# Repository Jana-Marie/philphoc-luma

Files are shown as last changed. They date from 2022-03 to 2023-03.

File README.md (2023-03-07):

# philphoc-luma

Philphoc-luma is a ZigBee (e.g. Philips Hue) to addressable LED-strip (e.g. WS2812, SK6812) bridge. It is based on an E75-2G4M20S and a STM32G030.

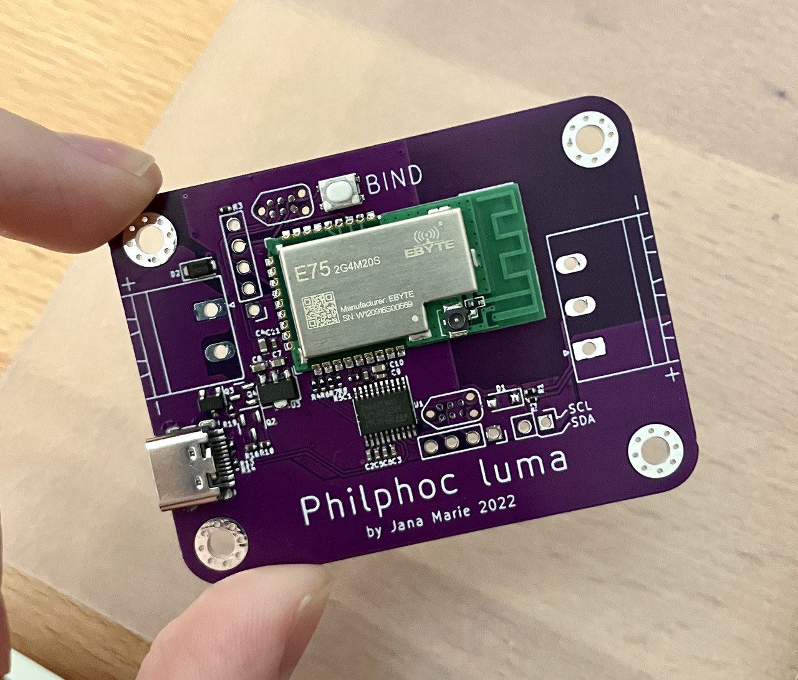
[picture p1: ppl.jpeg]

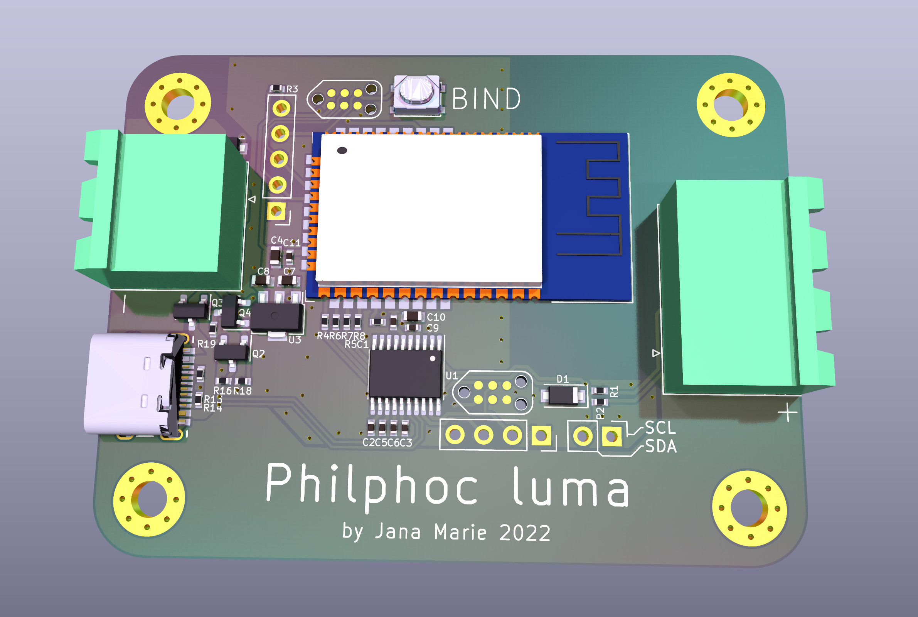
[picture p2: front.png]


## Firmware

There are two firmwares to be flashed, one for the STM32 and one for the E75-2G4M20S.

### ESP32

This is a simple GCC and Make based project, refer to the makefile and use your favourite flasher.

### E75

Please refer to the awesome works of PeeVeeOne to flash Light_ColorLight_JN5168_RGB onto the E75-2G4M20S module.

## License

Copyright Jana Marie Hemsing 2023. This source describes Open Hardware and is licensed under the CERN- OHL-S v2.

You may redistribute and modify this source and make products using it under the terms of the CERN-OHL-S v2 (LICENSE).

This source is distributed WITHOUT ANY EXPRESS OR IMPLIED WARRANTY, INCLUDING OF MERCHANTABILITY, SATISFACTORY QUALITY AND FITNESS FOR A PARTICULAR PURPOSE. Please see the CERN-OHL-S v2 for applicable conditions.

Source location: https://github.com/Jana-Marie/philphoc-luma As per CERN-OHL-S v2 section 4, should You produce hardware based on this source, You must where practicable maintain the Source Location visible on the external case of philphoc-luma or other products you make using this source

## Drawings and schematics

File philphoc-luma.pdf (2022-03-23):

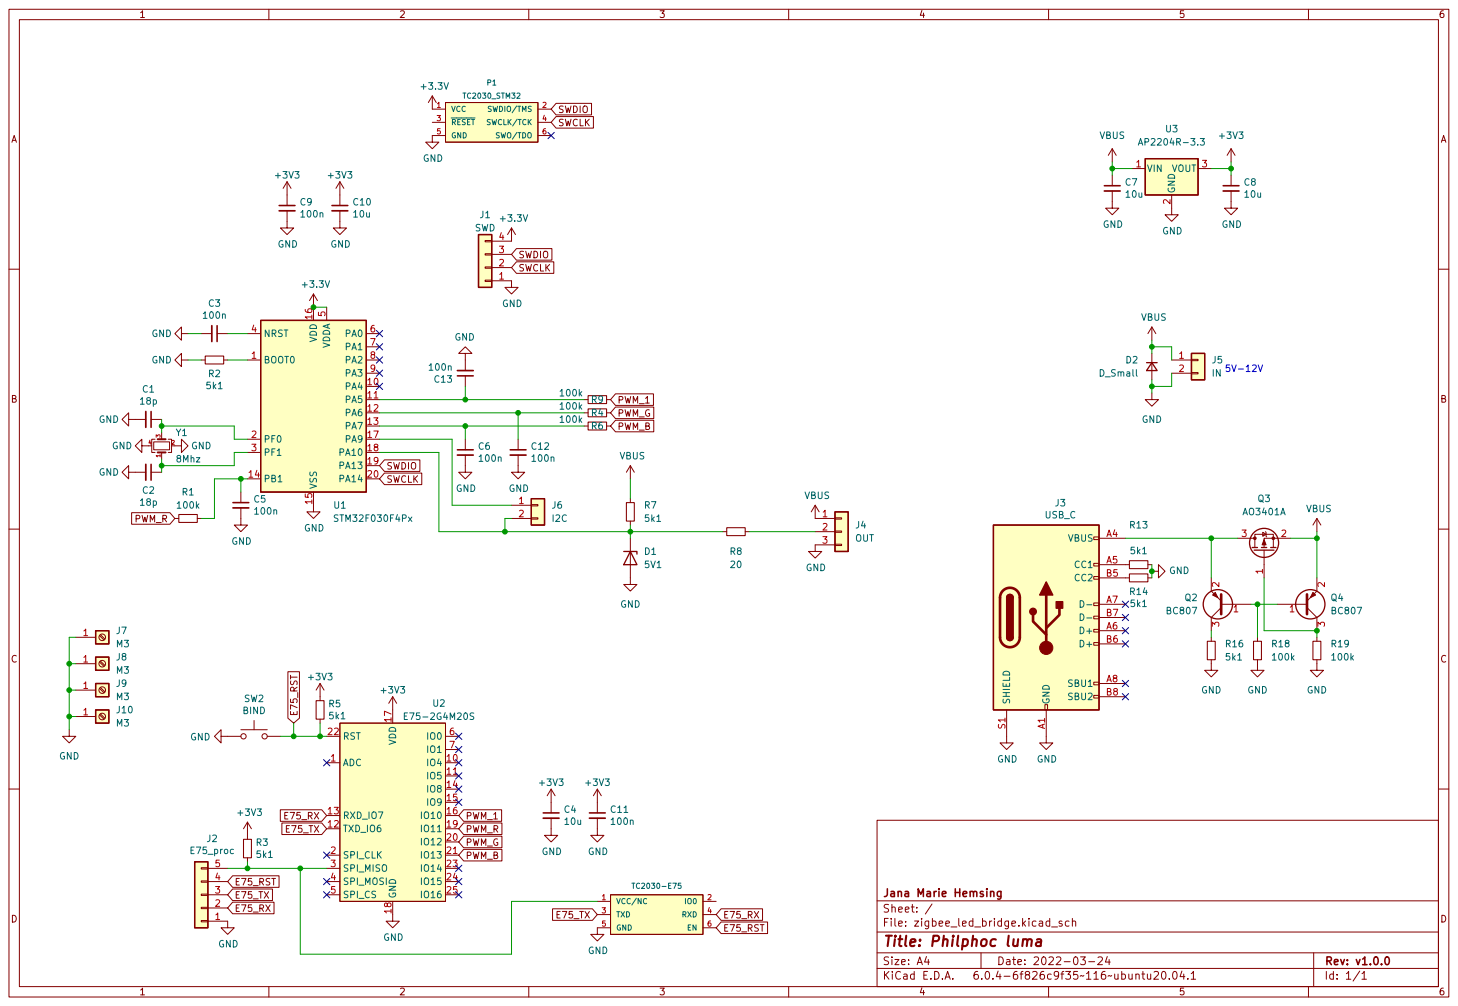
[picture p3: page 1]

J1 SWD GND GND GND

File: zigbee_led_bridge.kicad_sch Sheet: / Jana Marie Hemsing

Id: 1/1 Title: Philphoc luma

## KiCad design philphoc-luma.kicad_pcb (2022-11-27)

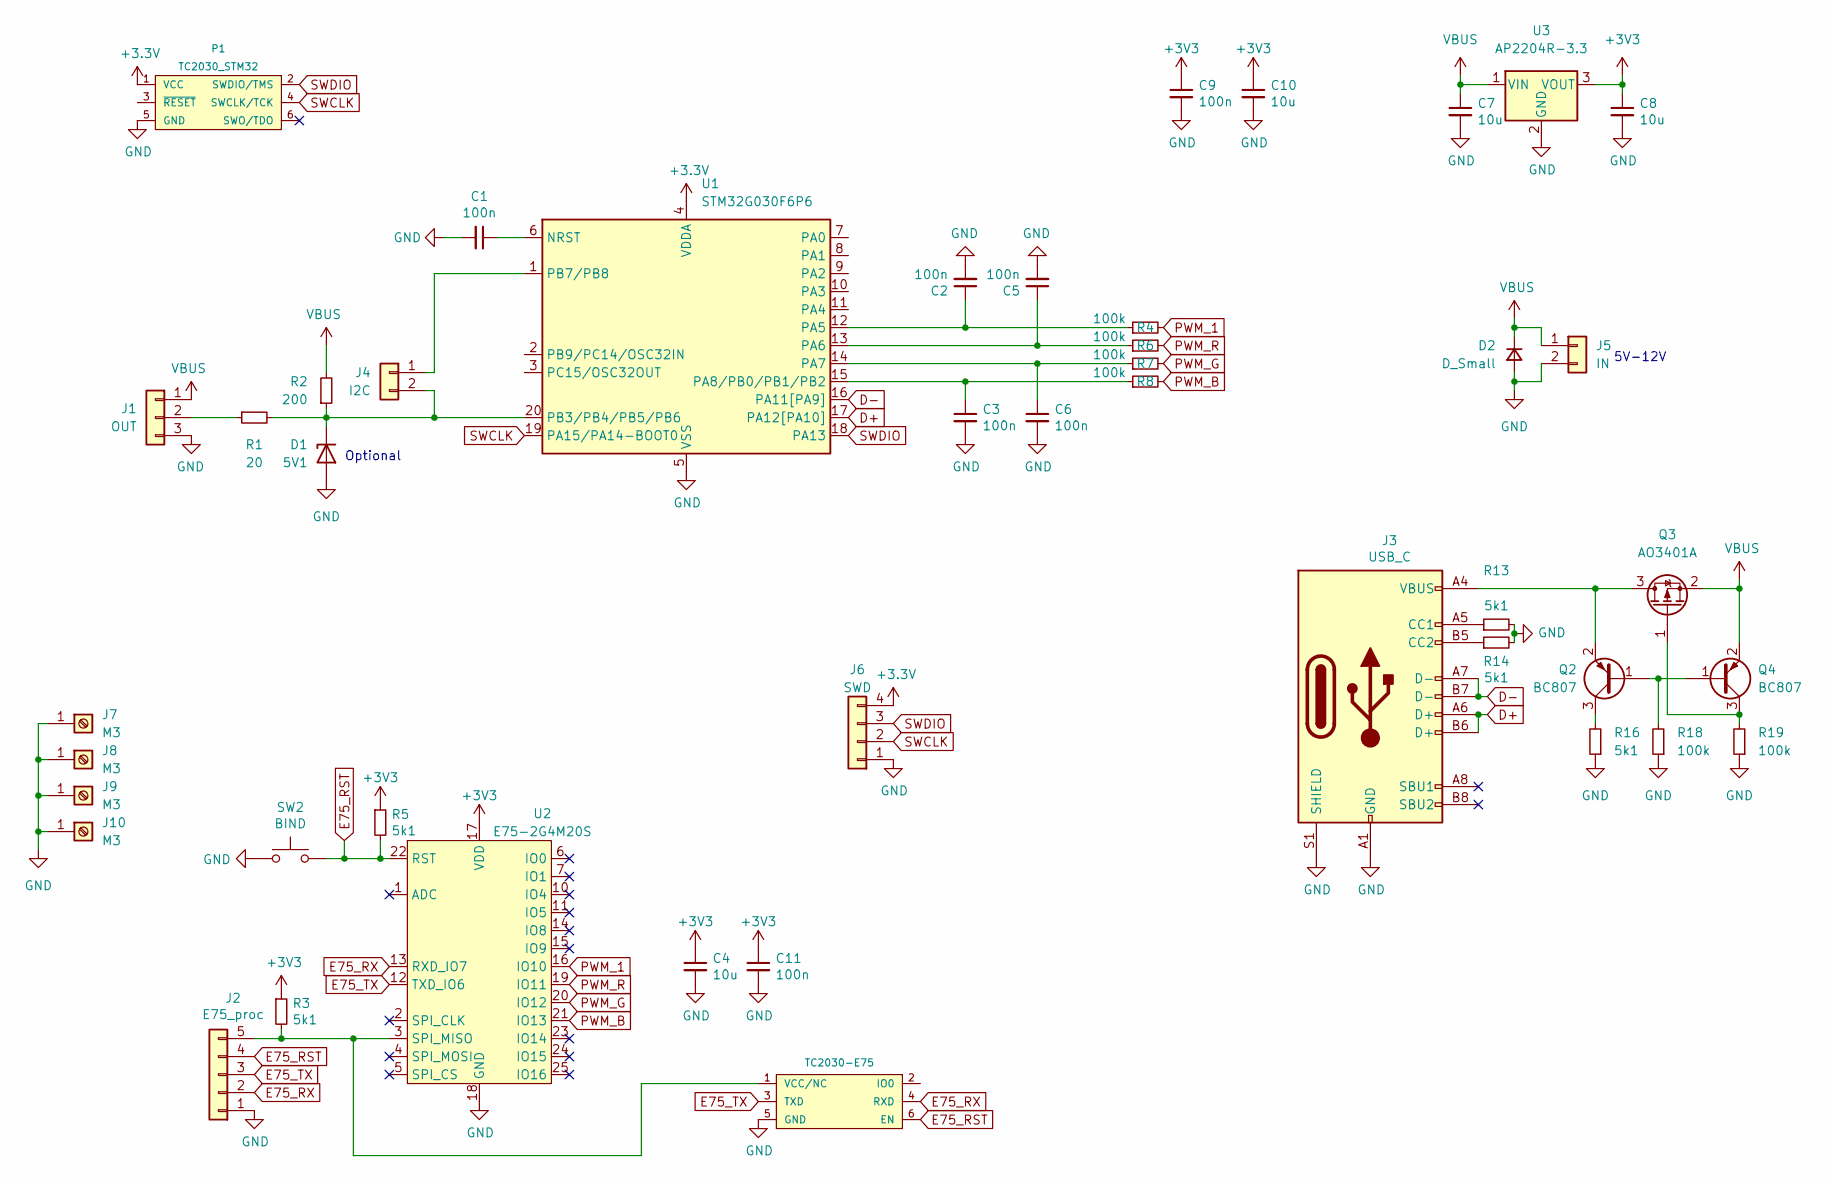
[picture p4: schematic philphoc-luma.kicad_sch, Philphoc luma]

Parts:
C1, C2, C3, C5, C6, C9, C11: 100n; C_0402
C4, C7, C8, C10: 10u; C_0603
D1: 5V1; D_SOD-123F
D2: D_Small; D_SOD-123F
J1: OUT; PhoenixContact_MSTBA_2,5_3-G-5,08_1x03_P5.08mm_Horizontal
J2: E75_proc; PinHeader_1x05_P2.54mm_Vertical
J3: USB_C; USB-C 16Pin
J4: I2C; PinHeader_1x02_P2.54mm_Vertical
J5: IN; PhoenixContact_MSTBA_2,5_2-G-5,08_1x02_P5.08mm_Horizontal
J6: SWD; PinSocket_1x04_P2.54mm_Vertical_center
J7, J8, J9, J10: M3; MountingHole_3.2mm_M3_Pad_Via
P1: TC2030_STM32; TC2030
P2: TC2030-E75; TC2030
Q2, Q4: BC807; SOT-23
Q3: AO3401A; SOT-23
R1: 20; R_0402
R2: 200; R_0402
R3, R5, R13, R14, R16: 5k1; R_0402
R4, R6, R7, R8, R18, R19: 100k; R_0402
SW2: BIND; SW_SPST_PTS810
U1: STM32G030F6P6; TSSOP-20_4.4x6.5mm_P0.65mm
U2: E75-2G4M20S; E75-2G4M10S
U3: AP2204R-3.3; SOT-89-3

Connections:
D+: J3.A6 (D+), J3.B6 (D+), U1.17 (PA12[PA10])
D-: J3.A7 (D-), J3.B7 (D-), U1.16 (PA11[PA9])
E75_RST: J2.4, P2.6 (EN), R5.2, SW2.2, U2.22 (RST)
E75_RX: J2.2, P2.4 (RXD), U2.13 (RXD_IO7)
E75_TX: J2.3, P2.3 (TXD), U2.12 (TXD_IO6)
GND: C1.2, C2.2, C3.2, C4.2, C5.2, C6.2, C7.2, C8.2, C9.2, C10.2, C11.2, D1.2 (A), D2.2 (A), J1.3, J2.1, J3.A1 (GND), J3.A12 (GND), J3.B1 (GND), J3.B12 (GND), J3.S1 (SHIELD), J5.2, J6.1, J7.1, J8.1, J9.1, J10.1, P1.5 (GND), P2.5 (GND), R13.2, R14.2, R16.1, R18.1, R19.1, SW2.1, U1.5 (VSS), U2.18 (GND), U3.2 (GND)
unnamed: C1.1, U1.6 (NRST)
unnamed: C2.1, R4.1, U1.12 (PA5)
unnamed: C3.1, R8.1, U1.15 (PA8/PB0/PB1/PB2)
unnamed: C5.1, R6.1, U1.13 (PA6)
unnamed: C6.1, R7.1, U1.14 (PA7)
unnamed: D1.1 (K), J4.2, R1.2, R2.1, U1.20 (PB3/PB4/PB5/PB6)
unnamed: J1.2, R1.1
unnamed: J2.5, P2.1 (VCC/NC), R3.2, U2.3 (SPI_MISO)
unnamed: J3.A4 (VBUS), J3.A9 (VBUS), J3.B4 (VBUS), J3.B9 (VBUS), Q2.2 (E), Q3.3 (D)
unnamed: J3.A5 (CC1), R13.1
unnamed: J3.B5 (CC2), R14.1
unnamed: J4.1, U1.1 (PB7/PB8)
unnamed: Q2.1 (B), Q4.1 (B), R18.2
unnamed: Q2.3 (C), R16.2
unnamed: Q3.1 (G), Q4.3 (C), R19.2
PWM_1: R4.2, U2.16 (IO10)
PWM_B: R8.2, U2.21 (IO13)
PWM_G: R7.2, U2.20 (IO12)
PWM_R: R6.2, U2.19 (IO11)
SWCLK: J6.2, P1.4 (SWCLK/TCK), U1.19 (PA15/PA14-BOOT0)
SWDIO: J6.3, P1.2 (SWDIO/TMS), U1.18 (PA13)
VBUS: C7.1, D2.1 (K), J1.1, J5.1, Q3.2 (S), Q4.2 (E), R2.2, U3.1 (VIN)

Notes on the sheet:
Optional
5V-12V

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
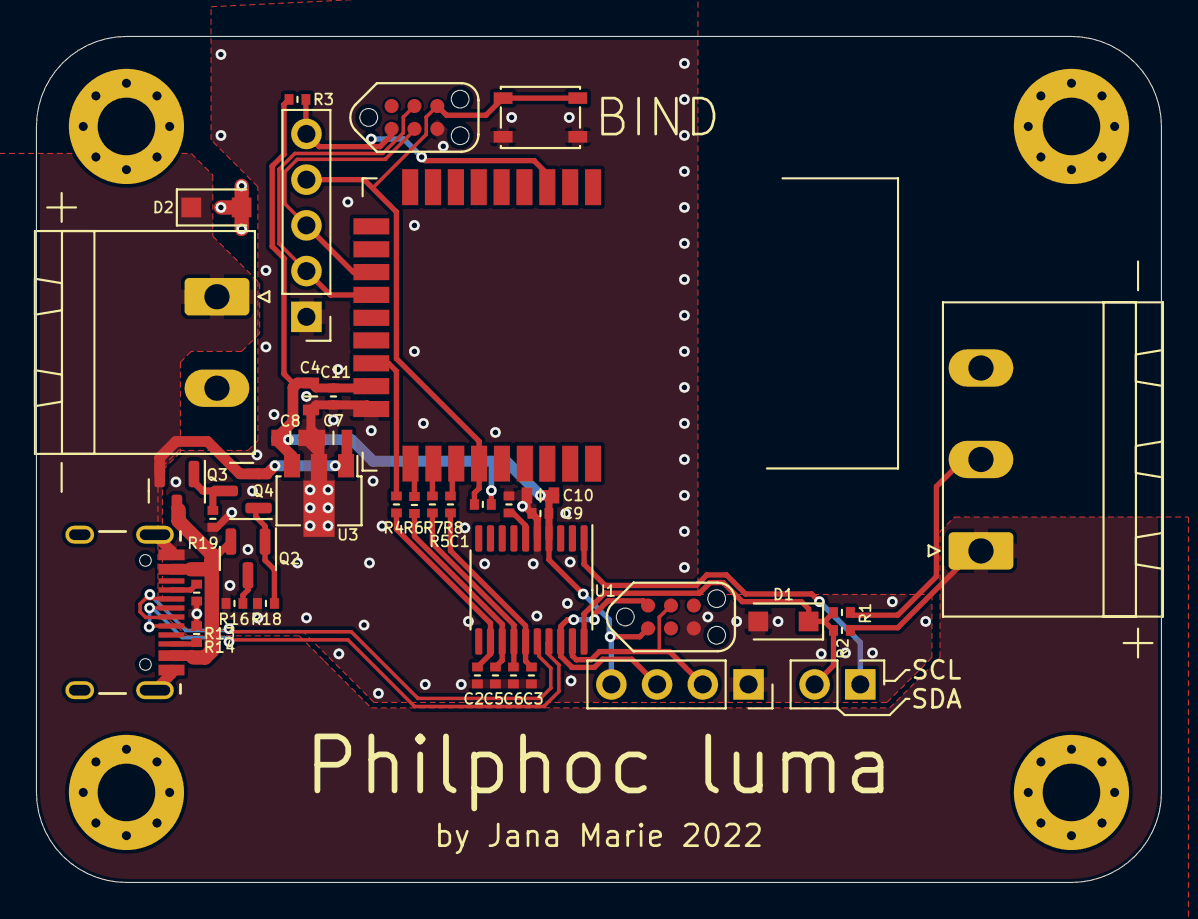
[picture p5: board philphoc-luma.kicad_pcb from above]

Board: 2 copper layers, 62.5 x 47.0 mm, 45 parts (0 on the bottom side), 29 nets.

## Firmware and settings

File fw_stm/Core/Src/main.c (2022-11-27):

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
/* Includes ------------------------------------------------------------------*/
#include "main.h"

/* USER CODE BEGIN Includes */
#include <string.h>
/* USER CODE END Includes */

ADC_HandleTypeDef hadc1;
DMA_HandleTypeDef hdma_adc1;

SPI_HandleTypeDef hspi1;
DMA_HandleTypeDef hdma_spi1_tx;

TIM_HandleTypeDef htim3;

void SystemClock_Config(void);
static void MX_GPIO_Init(void);
static void MX_DMA_Init(void);
static void MX_TIM3_Init(void);
static void MX_SPI1_Init(void);
static void MX_ADC1_Init(void);
/* USER CODE BEGIN PFP */
#define WS2812_NUM_LEDS 120
#define WS2812_SPI_HANDLE hspi1

#define WS2812_RESET_PULSE 60
#define WS2812_BUFFER_SIZE (WS2812_NUM_LEDS * 24 + WS2812_RESET_PULSE)

uint8_t ws2812_buffer[WS2812_BUFFER_SIZE];

void ws2812_init(void);
void ws2812_send_spi(void);
void ws2812_pixel(uint16_t led_no, uint8_t r, uint8_t g, uint8_t b);
void ws2812_pixel_all(uint8_t r, uint8_t g, uint8_t b);
long map(long x, long in_min, long in_max, long out_min, long out_max);

int16_t adc_color[4];
int16_t adc_filt[3];
uint8_t hue_color[3];

uint16_t wakeup;
/* USER CODE END PFP */

/**
  * @brief  The application entry point.
  * @retval int
  */
int main(void)
{
  /* MCU Configuration--------------------------------------------------------*/

  /* Reset of all peripherals, Initializes the Flash interface and the Systick. */
  HAL_Init();

  /* Configure the system clock */
  SystemClock_Config();

  /* Initialize all configured peripherals */
  MX_GPIO_Init();
  MX_DMA_Init();
  MX_TIM3_Init();
  MX_SPI1_Init();
  MX_ADC1_Init();
  /* USER CODE BEGIN 2 */
  ws2812_init();
  HAL_ADC_Start_DMA(&hadc1, (uint32_t *) adc_color, 4);
  HAL_TIM_Base_Start(&htim3);
  /* USER CODE END 2 */

  /* Infinite loop */
  /* USER CODE BEGIN WHILE */
  while (1)
  {
    adc_filt[0] = adc_filt[0] * 0.98 + adc_color[1] * 0.02;
    adc_filt[1] = adc_filt[1] * 0.98 + adc_color[2] * 0.02;
    adc_filt[2] = adc_filt[2] * 0.98 + adc_color[3] * 0.02;
    if (adc_color[1] >= 4094 && adc_color[2] >= 4094 && adc_color[3] >= 4094) {
      hue_color[0] = 0;
      hue_color[1] = 0;
      hue_color[2] = 0;
      wakeup = 50;
      ws2812_pixel_all(0,0,0);
      HAL_Delay(50);
    } else {
      hue_color[0] = map(adc_filt[0], 0, 4070, wakeup, 0);
      hue_color[1] = map(adc_filt[1], 0, 4070, wakeup, 0);
      hue_color[2] = map(adc_filt[2], 0, 4070, wakeup, 0);
      wakeup++;
      if (wakeup > 255) {
        wakeup = 255;
      }
      ws2812_pixel_all(hue_color[0], hue_color[1], hue_color[2]);
      HAL_Delay(1);
    }
    ws2812_send_spi();
    /* USER CODE END WHILE */

    /* USER CODE BEGIN 3 */
  }
  /* USER CODE END 3 */
}

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
/* USER CODE BEGIN 4 */
// based on https://www.newinnovations.nl/post/controlling-ws2812-and-ws2812b-using-only-stm32-spi/
void ws2812_init(void) {
    memset(ws2812_buffer, 0, WS2812_BUFFER_SIZE);
    ws2812_send_spi();
}

void ws2812_send_spi(void) {
    HAL_SPI_Transmit_DMA(&WS2812_SPI_HANDLE, ws2812_buffer, WS2812_BUFFER_SIZE);
}

#define WS2812_FILL_BUFFER(COLOR) \
    for( uint8_t mask = 0x80; mask; mask >>= 1 ) { \
        if( COLOR & mask ) { \
            *ptr++ = 0xf8; \
        } else { \
            *ptr++ = 0x80; \
        } \
    }

void ws2812_pixel(uint16_t led_no, uint8_t r, uint8_t g, uint8_t b) {
    uint8_t * ptr = &ws2812_buffer[24 * led_no];
    WS2812_FILL_BUFFER(g);
    WS2812_FILL_BUFFER(r);
    WS2812_FILL_BUFFER(b);
}

void ws2812_pixel_all(uint8_t r, uint8_t g, uint8_t b) {
    uint8_t * ptr = ws2812_buffer;
    for( uint16_t i = 0; i < WS2812_NUM_LEDS; ++i) {
        WS2812_FILL_BUFFER(g);
        WS2812_FILL_BUFFER(r);
        WS2812_FILL_BUFFER(b);
    }
}

long map(long x, long in_min, long in_max, long out_min, long out_max){
  return (x - in_min) * (out_max - out_min) / (in_max - in_min) + out_min;
}
/* USER CODE END 4 */
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


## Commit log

2022-03-23 added kicad files
    [philphoc-luma.kicad_pcb, philphoc-luma.kicad_sch]
2022-03-23 added schematic pdf
2022-03-24 exchanged STM32f030 for STM32G030
    [philphoc-luma.kicad_pcb, philphoc-luma.kicad_sch]
2022-03-24 updated gerber
    [philphoc-luma-B_Cu.gbl, philphoc-luma-B_Mask.gbs, philphoc-luma-B_Paste.gbp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]
2022-11-24 removed files
    [philphoc-luma-B_Cu.gbl, philphoc-luma-B_Mask.gbs, philphoc-luma-B_Paste.gbp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]
2022-11-27 updated sch
    [philphoc-luma.kicad_sch]
2022-11-27 created rendering
    [philphoc-luma.kicad_pcb]

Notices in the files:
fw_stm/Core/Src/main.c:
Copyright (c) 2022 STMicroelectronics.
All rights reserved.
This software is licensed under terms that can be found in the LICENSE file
